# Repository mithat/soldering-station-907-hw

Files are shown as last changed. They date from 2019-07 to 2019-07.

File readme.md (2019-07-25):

Soldering Station 907
---------------------

Mithat Konar

A PCB implementation for [sfrwmaker/soldering_907_lcd
](https://github.com/sfrwmaker/soldering_907_lcd) using a 1602 LCD.

Note: After starting this, I discovered that the supply of decent 907-style handles has really dried up. So I'm probably going to leave this unfinished and instead do what all the cool kids are doing and move to something using a T12-style handle.

---------------------------------

I've tried to keep as close to sfrwmaker's original schematic as possible, but I made some changes to reflect best practices. In particular:

* I've added some additional 0.1u bypass capacitors.
* All the buzzers I looked at drew current that was uncomfortably close or exceeded the ATmega328p's absolute maximum of 40mA. So I adopted an easy to source (in the USA, anyway) buzzer (without internal oscillator) and added a driver circuit that offloads the Nano.

Some notes:
* Symbols that aren't found in the default KiCad 5.x distributions are in `local.lib`. Footprints not found in the default KiCad 5.x distributions are in `local.pretty`. If KiCad barks at you about missing things, add these to the project using the respective symbol and footprint managers.
* A custom Arduino Nano symbol was needed to make the design pass DRC. Specifically, the +5V power output pin was made a power input to reflect how that pin is being used here.
* Something better suited to the design than the inexpensive eBay [LM2596 DC-DC module](https://www.ebay.com/itm/10-PCS-LM2596-DC-DC-buck-adjustable-step-down-Power-Supply-Converter-module-/221920170517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) is very likely, but I used this because the original designer did so  in their [Hackster.io project](https://www.hackster.io/sfrwmaker/soldering-iron-controller-for-hakko-907-v-2-fc75d7). **The footprint for this part is currently not correct.** The outer dimensions were taken from an eBay posting, and the pad and mounting hole locations and sizes are wild guesses from images.
* Better alternatives to the MCP602 (and AD822) are probably available, but again I am sticking as much as possible to the original design.

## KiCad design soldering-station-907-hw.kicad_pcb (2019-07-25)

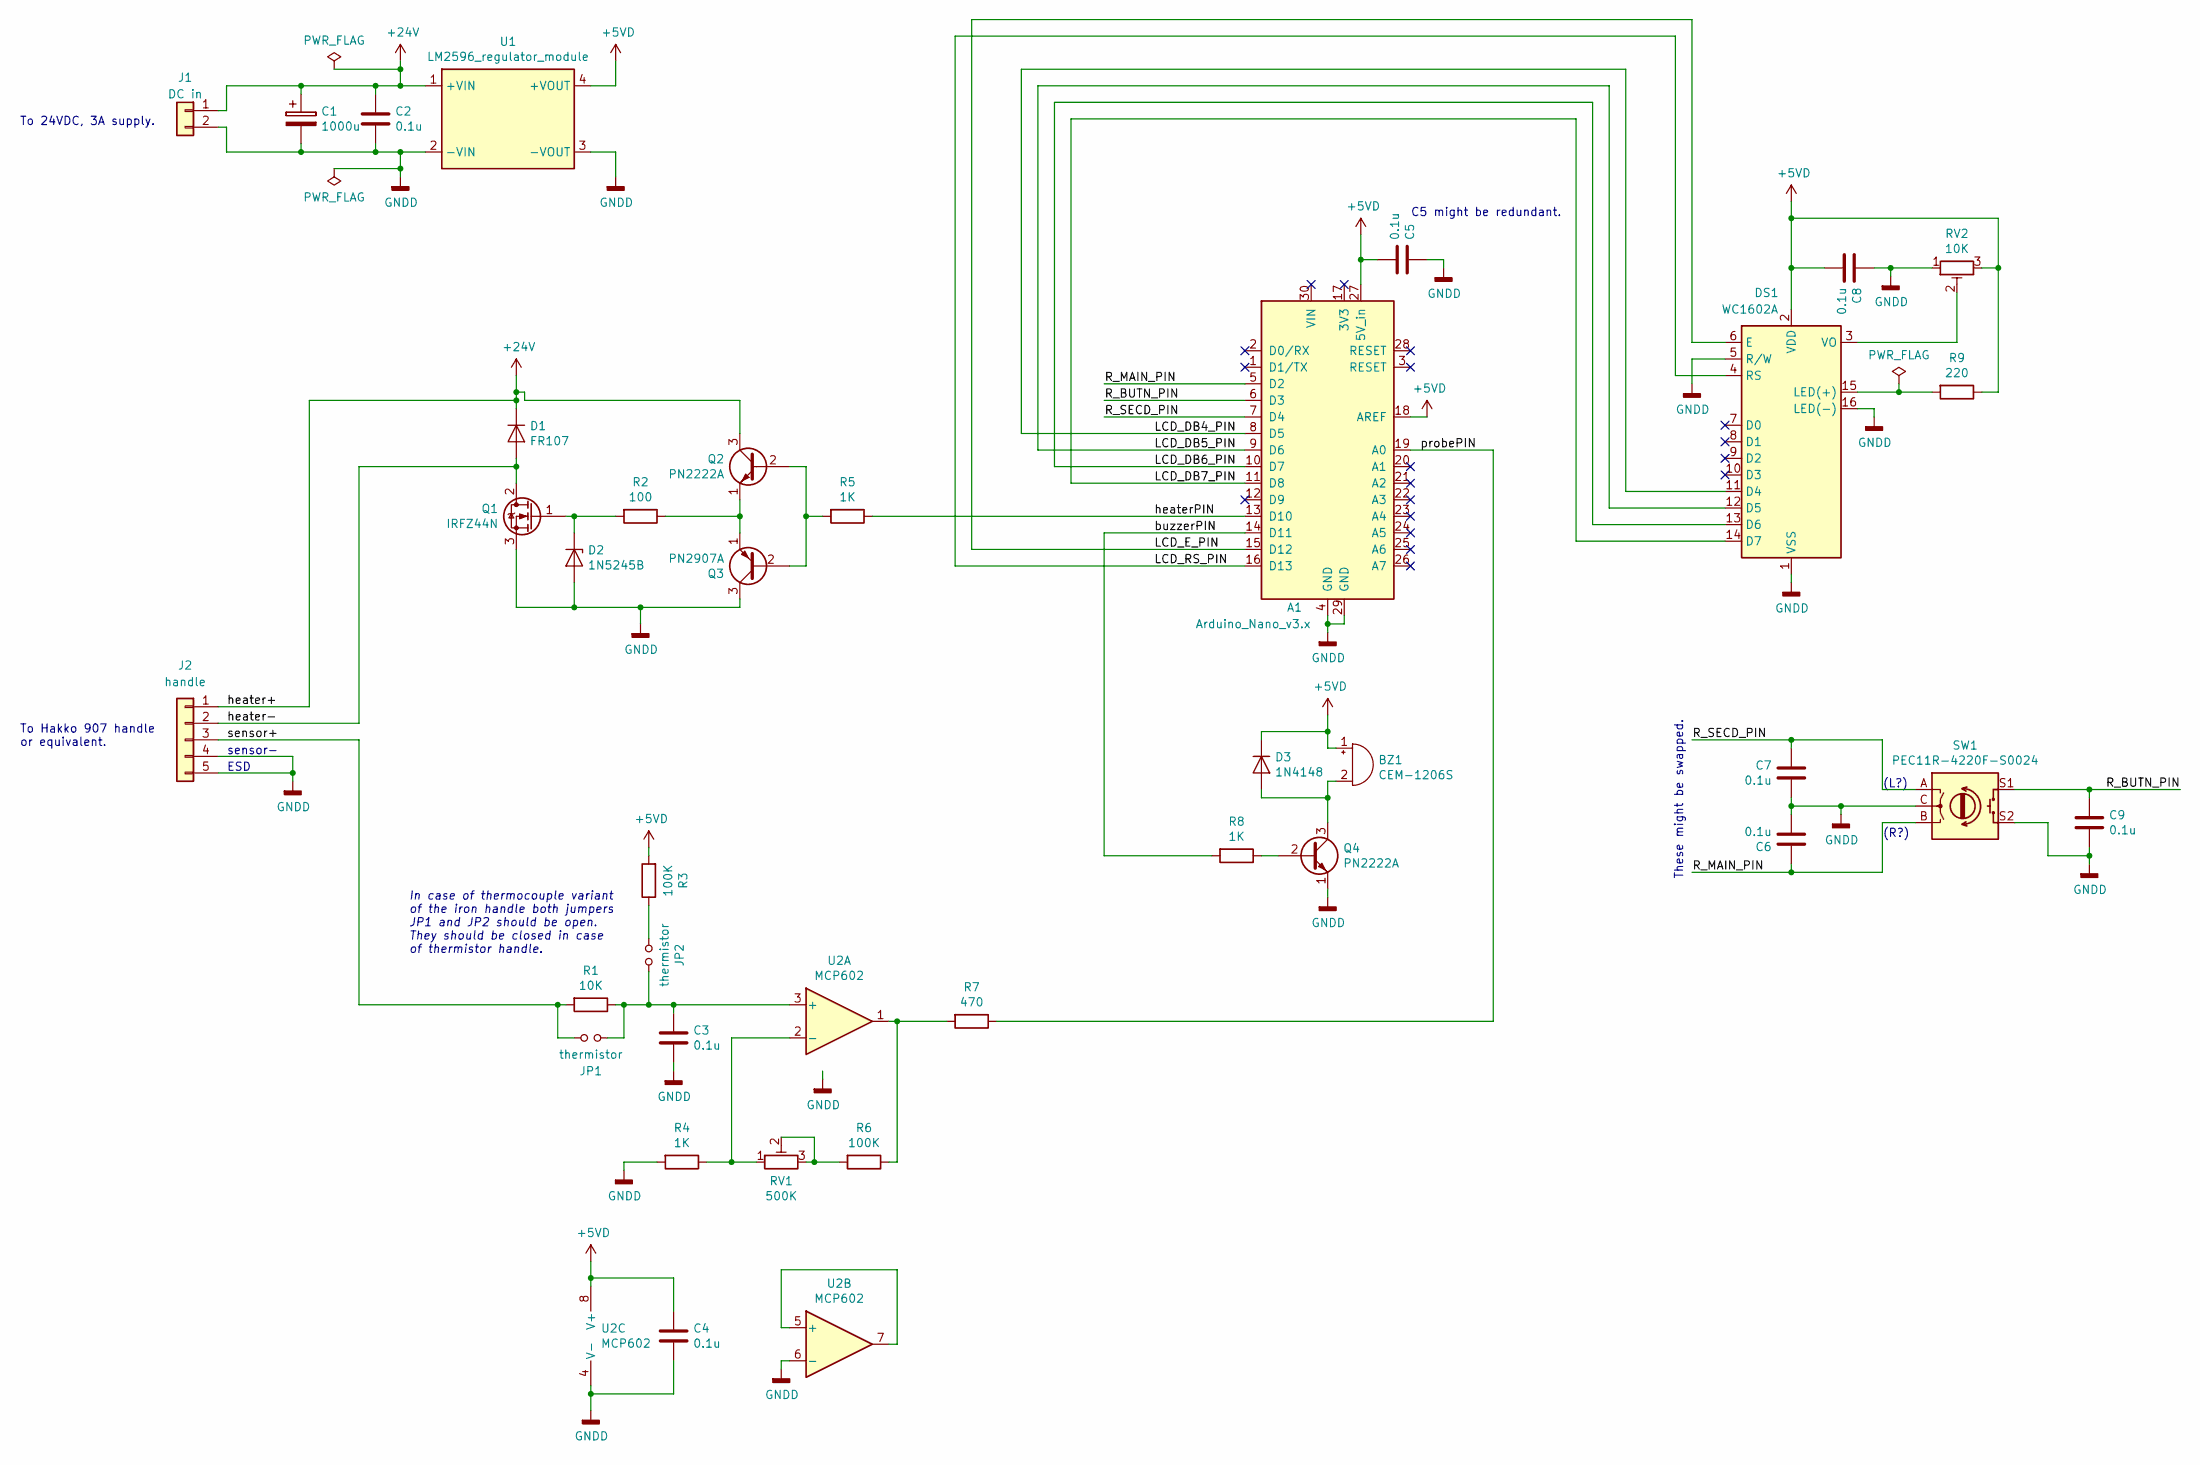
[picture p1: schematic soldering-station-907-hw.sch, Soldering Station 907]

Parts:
A1: Arduino_Nano_v3.x; Arduino_Nano_WithMountingHoles
BZ1: CEM-1206S; MagneticBuzzer_ProSignal_ABT-410-RC
C1: 1000u; CP_Radial_D12.5mm_P5.00mm
C2, C3, C4, C5, C6, C7, C8, C9: 0.1u; C_Rect_L4.0mm_W2.5mm_P2.50mm
D1: FR107; D_DO-41_SOD81_P10.16mm_Horizontal
D2: 1N5245B; D_DO-35_SOD27_P7.62mm_Horizontal
D3: 1N4148; D_DO-35_SOD27_P7.62mm_Horizontal
DS1: WC1602A
J1: DC in; JST_VH_B2P-VH-FB-B_1x02_P3.96mm_Vertical
J2: handle; JST_VH_B5P-VH-FB-B_1x05_P3.96mm_Vertical
JP1, JP2: thermistor; PinHeader_1x02_P2.54mm_Vertical
Q1: IRFZ44N; TO-220-3_Vertical
Q2, Q4: PN2222A; TO-92_HandSolder
Q3: PN2907A; TO-92_HandSolder
R1: 10K; R_Axial_DIN0207_L6.3mm_D2.5mm_P10.16mm_Horizontal
R2: 100; R_Axial_DIN0207_L6.3mm_D2.5mm_P10.16mm_Horizontal
R3, R6: 100K; R_Axial_DIN0207_L6.3mm_D2.5mm_P10.16mm_Horizontal
R4, R5, R8: 1K; R_Axial_DIN0207_L6.3mm_D2.5mm_P10.16mm_Horizontal
R7: 470; R_Axial_DIN0207_L6.3mm_D2.5mm_P10.16mm_Horizontal
R9: 220; R_Axial_DIN0207_L6.3mm_D2.5mm_P10.16mm_Horizontal
RV1: 500K; Potentiometer_Bourns_3296W_Vertical
RV2: 10K; Potentiometer_Bourns_3386F_Vertical
SW1: PEC11R-4220F-S0024; RotaryEncoder_Alps_EC12E-Switch_Vertical_H20mm
U1: LM2596_regulator_module
U2: MCP602; DIP-8_W7.62mm_Socket_LongPads

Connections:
+5VD: A1.18 (AREF), A1.27 (5V_in), BZ1.1 (-), C4.1, C5.2, C8.2, D3.1 (K), DS1.2 (VDD), R3.2, R9.1, RV2.3, U1.4 (+VOUT), U2.8 (V+)
+24V: C1.1, C2.1, D1.1 (K), J1.1, J2.1, Q2.3 (C), U1.1 (+VIN)
/LCD_DB4_PIN: A1.8 (D5), DS1.11 (D4)
/LCD_DB5_PIN: A1.9 (D6), DS1.12 (D5)
/LCD_DB6_PIN: A1.10 (D7), DS1.13 (D6)
/LCD_DB7_PIN: A1.11 (D8), DS1.14 (D7)
/LCD_E_PIN: A1.15 (D12), DS1.6 (E)
/LCD_RS_PIN: A1.16 (D13), DS1.4 (RS)
/R_BUTN_PIN: A1.6 (D3), C9.1, SW1.S1
/R_MAIN_PIN: A1.5 (D2), C6.1, SW1.B
/R_SECD_PIN: A1.7 (D4), C7.1, SW1.A
/buzzerPIN: A1.14 (D11), R8.2
/heater-: D1.2 (A), J2.2, Q1.2 (D)
/heaterPIN: A1.13 (D10), R5.1
/probePIN: A1.19 (A0), R7.1
/sensor+: J2.3, JP1.1, R1.2
GNDD: A1.4 (GND), A1.29 (GND), C1.2, C2.2, C3.2, C4.2, C5.1, C6.2, C7.2, C8.1, C9.2, D2.2 (A), DS1.1 (VSS), DS1.5 (R/W), DS1.16 (LED(-)), J1.2, J2.4, J2.5, Q1.3 (S), Q3.3 (C), Q4.1 (E), R4.2, RV2.1, SW1.C, SW1.S2, U1.2 (-VIN), U1.3 (-VOUT), U2.4 (V-), U2.6 (-)
unnamed: BZ1.2 (+), D3.2 (A), Q4.3 (C)
unnamed: C3.1, JP1.2, JP2.2, R1.1, U2.3 (+)
unnamed: D2.1 (K), Q1.1 (G), R2.2
unnamed: DS1.3 (VO), RV2.2
unnamed: DS1.15 (LED(+)), R9.2
unnamed: JP2.1, R3.1
unnamed: Q2.1 (E), Q3.1 (E), R2.1
unnamed: Q2.2 (B), Q3.2 (B), R5.2
unnamed: Q4.2 (B), R8.1
unnamed: R4.1, RV1.1, U2.2 (-)
unnamed: R6.1, R7.2, U2.1
unnamed: R6.2, RV1.2, RV1.3
unnamed: U2.5 (+), U2.7

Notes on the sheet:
These might be swapped.
In case of thermocouple variant of the iron handle both jumpers JP1 and JP2 should be open. They should be closed in case of thermistor handle.
sensor-
ESD
To Hakko 907 handle or equivalent.
To 24VDC, 3A supply.
C5 might be redundant.
(R?)
(L?)

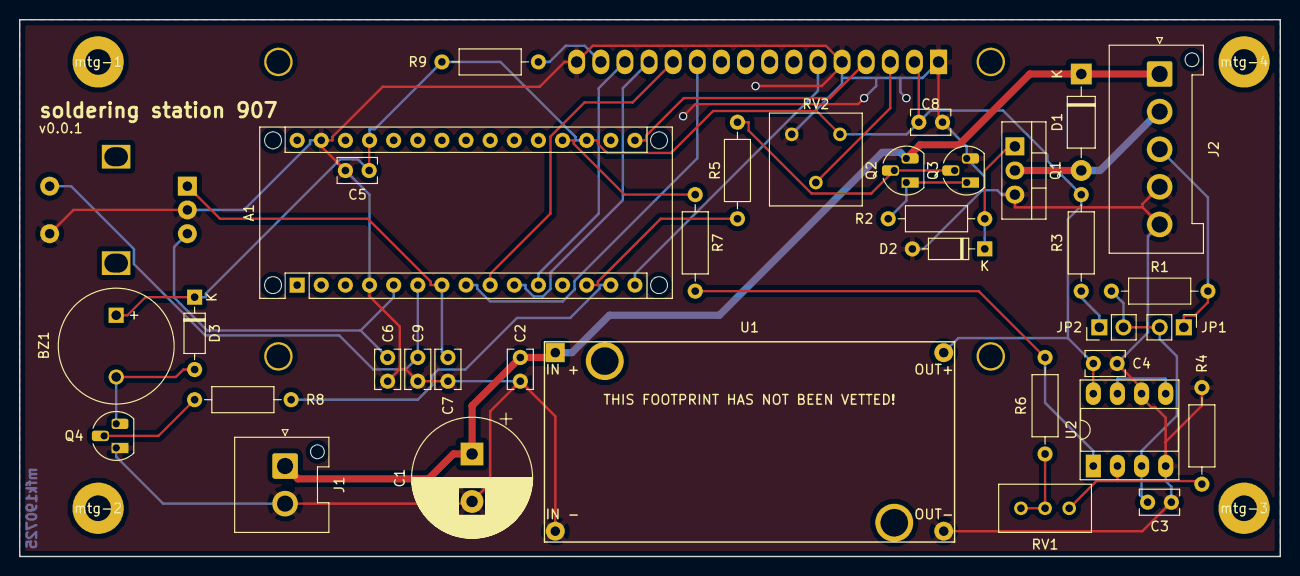
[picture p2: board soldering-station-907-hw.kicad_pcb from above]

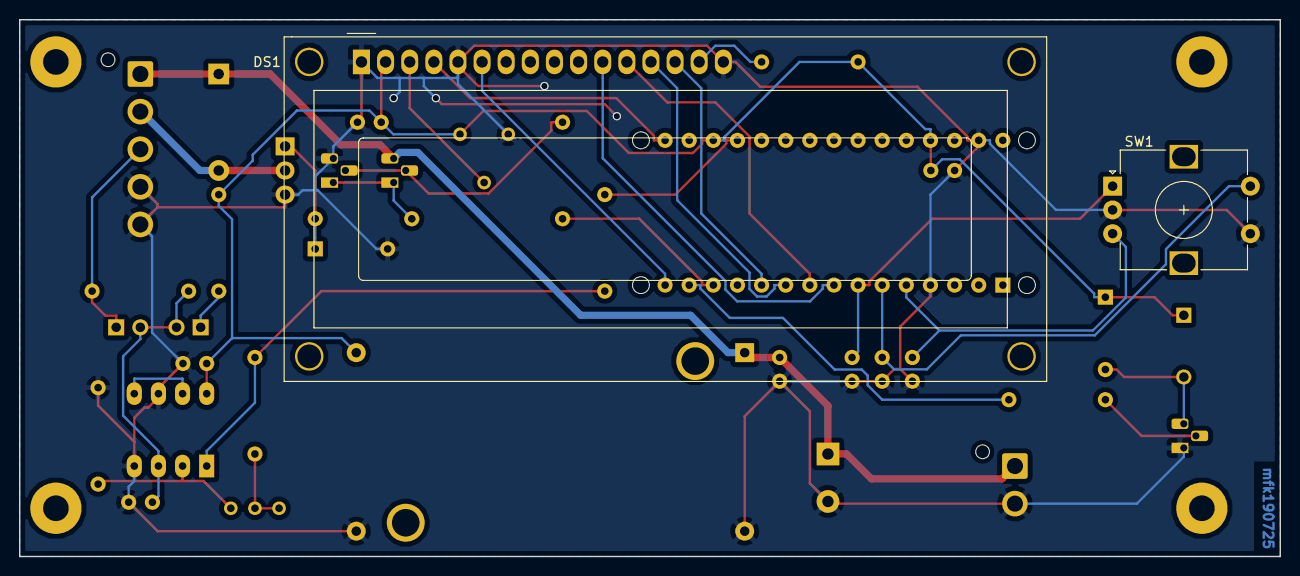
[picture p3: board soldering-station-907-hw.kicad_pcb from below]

Board: 2 copper layers, 132.7 x 56.5 mm, 41 parts (2 on the bottom side), 30 nets.

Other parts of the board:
mtg-1, mtg-2, mtg-3, mtg-4: MountingHole_2.7mm_M2.5_Pad

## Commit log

2019-07-25 Initial commit. Schematic complete.
    [soldering-station-907-hw.kicad_pcb, soldering-station-907-hw.sch]
2019-07-25 Parts placed.
    [soldering-station-907-hw.kicad_pcb, soldering-station-907-hw.sch]
2019-07-25 Copper pours.
    [soldering-station-907-hw.kicad_pcb]
2019-07-25 Silkscreen label.
    [soldering-station-907-hw.kicad_pcb]
2019-07-25 Swapped R/L pins of SW1. Moved RV1 to front of board. Routing tweaks.
    [soldering-station-907-hw.kicad_pcb, soldering-station-907-hw.sch]
